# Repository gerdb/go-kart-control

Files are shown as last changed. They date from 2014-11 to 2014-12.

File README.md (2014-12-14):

#Go-Kart Control  
####Radio controlled displays for go-kart tracks  
---
 
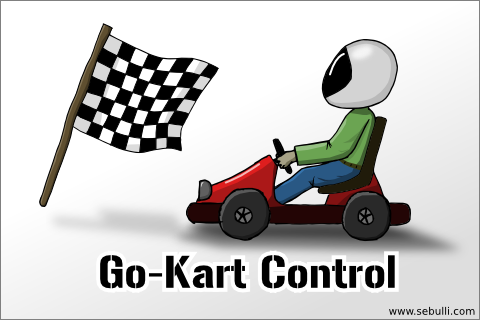
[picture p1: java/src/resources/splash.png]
slpash


##Install the Go-Kart-Control software
Download and unzip the ZIP archive containing all executables and also the source code:  
https://github.com/gerdb/go-kart-control/archive/master.zip  
On a windows system just start the executable **Go-Kart-Control.exe** in /install/win32 or win64  
On a Mac or Linux start the java JAR archive in install/all with **java - jar go-kart-control.jar**.  
Don't forget to set the correct serial port in settings.txt.  
Java must be installed: https://www.java.com/de/download/  

##Translation
You can translate the application.  
Open the *lang/messages.pot* file and translate it with http://poedit.net/  
Save the *messages_LANGUAGE_CODE.po* file in the *lang* folder of your program.  
Set the local code in *settings.txt*, if you don't want to use the system settings.

##Arduino software
If it's a new AVR, program it with the Arduino bootloader. For example with AVRDUDE:  
`avrdude -pm32u4 -cstk500 -P/dev/ttyUSB0 -e`  
`avrdude -pm32u4 -cstk500 -P/dev/ttyUSB0 -v -e -U lfuse:w:0xff:m -U hfuse:w:0xd8:m -U efuse:w:0xcb:m`  
`avrdude -pm32u4 -cstk500 -P/dev/ttyUSB0 -v -e -U flash:w:Caterina-Micro.hex -U lock:w:0x2F:m`

The Arduino project file is: **arduino/go_kart_panel/go_kart_panel.ino**

##Hardware setup
The PCB can be assembles in 2 variants: As a master module or as a panel module.  
The master module is connected to the PC.  
The panel module has a display.
The differences between both electronics are marked here:  
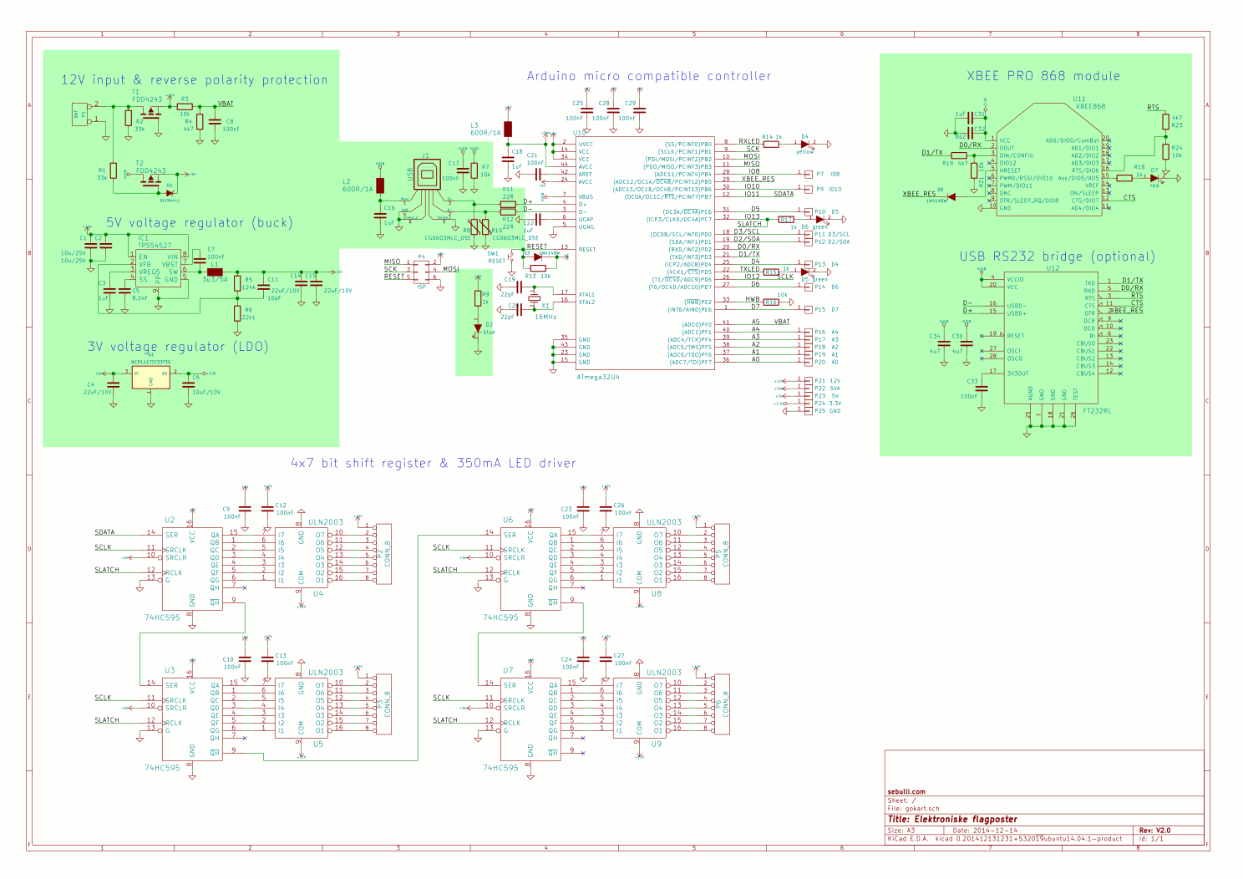
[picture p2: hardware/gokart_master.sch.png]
  
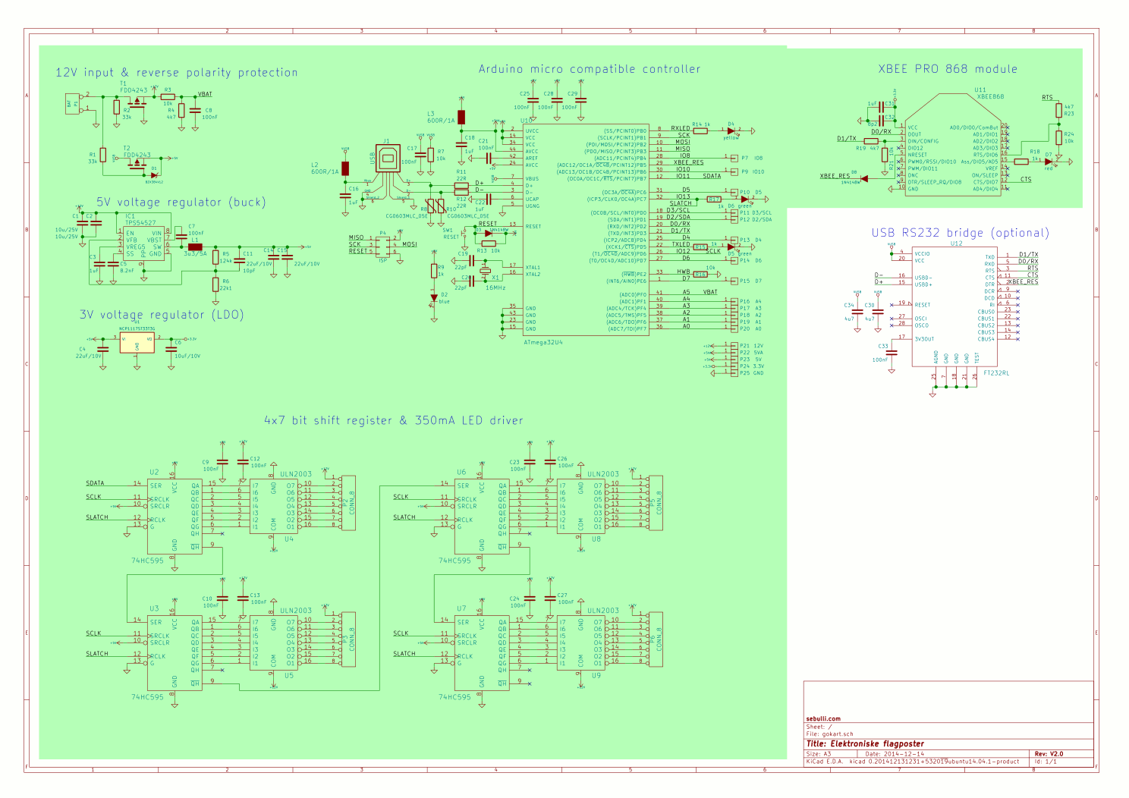
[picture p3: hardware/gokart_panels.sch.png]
  

###PCB layout
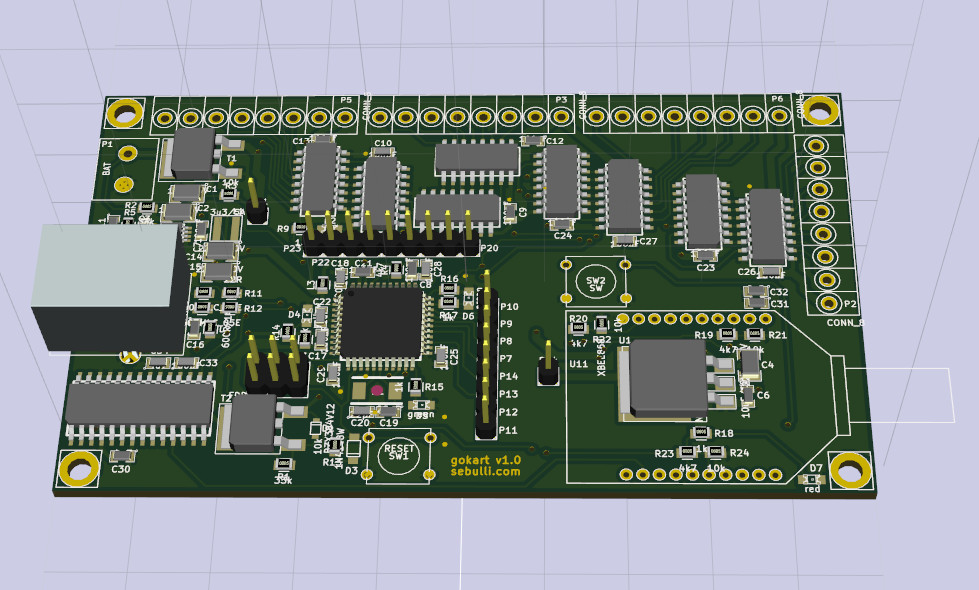
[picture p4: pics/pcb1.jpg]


###Master module
The master module is connected to a USB port of a PC or notebook. The master module can be supplied by USB or by an external 12V power supply. An external power supply is recommended on high power settings (If not, the blue LED is flickering). 

###Panel module
If there is a new master module, update the radio.ino file with the master's XBee address and download it to all panel modules. The panels will only accept data from this master.   
On startup, the software version, the battery voltage (120=12V) and the power setting (0..4) is displayed.  
The XBee module is ready when all LEDs blink for a short time.  
If then the testpoint P11 and P12 are connected together, the module displays the XBee address step by step and a display test is performed. Use this address to update the **settings.txt**  

Use 7-segment displays with common anode. Voltage is 12V. Use external resistors in each line **a**..**g**  
Connect LEDs to display the flag status. Connect the anode together.  
The maximum current for 7-segment display or LED is 300mA per line.

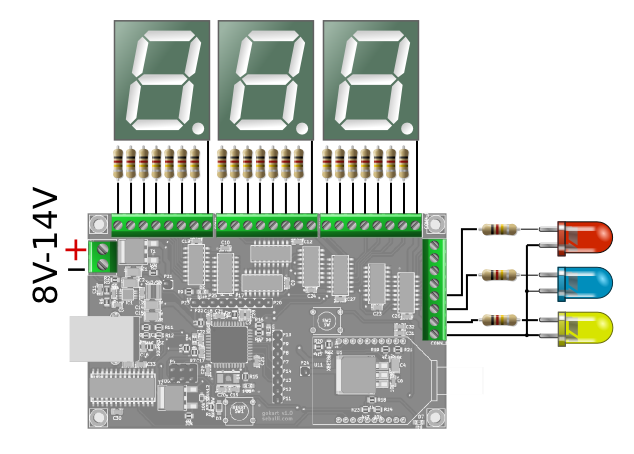
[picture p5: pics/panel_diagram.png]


##Your own Go-Kart track
You can use the /pics/track.svg to generate you own background images for your go-kart tracks.  
Edit this with Inkscape https://inkscape.org/de/ and export it as bitmap to your /pics folder. Filename is background.png.  
Edit the settings.txt and change the x and y position of your panels.  

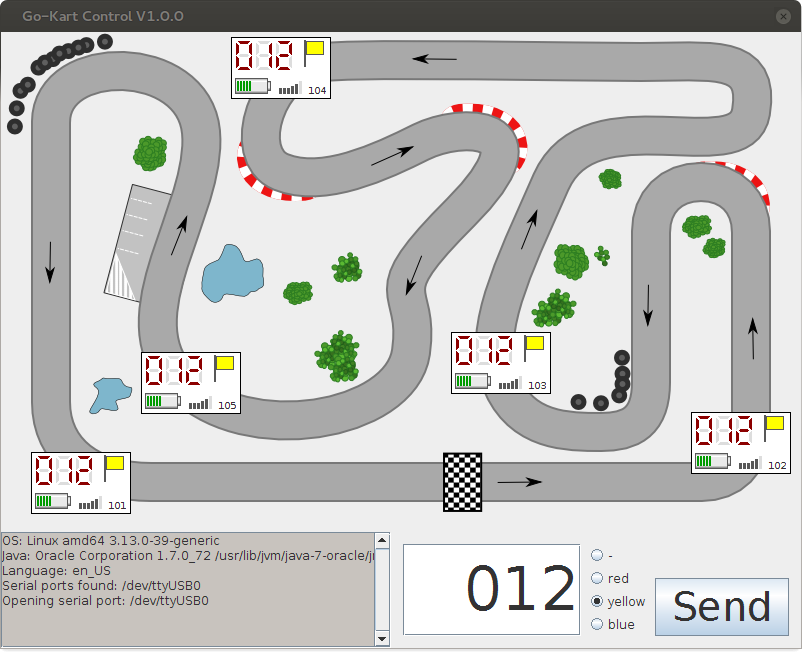
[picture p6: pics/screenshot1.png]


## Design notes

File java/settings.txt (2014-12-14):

# Configuration file for Go-kart control

# Set the language and country. For example to: da_DK.
# Leave it empty to use the system settings
locale :

# Set to 1, if main window should be always on top.
# Else set it to 0.
window.ontop : 0

# Set serial port
# For Windows it's something like COM1. See device manager.
# For Linux it's something like: ttyUSB0. See folder /dev/
port : ttyUSB0

# Enable the test mode
# 0: This value should set to 0, for normal operation
# 1: Test mode enabled. The RSSI value is displayed
testmode : 0

# Battery voltage
# The lower (empty) and upper limit (full) for battery voltage.
# Unit is volts.
battery.empty : 10.0
battery.full  : 13.5

# Signal strength indicator
# Unit is dbm
signal.poor : -110
signal.good : -60

# What to do, if send button was clicked
# nothing: Just send
# number : Clear the number field
# flag   : Clear the flag field
# all    : Clear both, number field and flag field
button.send.clear : all

# Time in seconds between 2 cycles of communicate with all panels
communication.pause : 0

# How many times should a transmission be repeated
communication.repeat : 3

# Set the power level from 0 .. 4  (0=1mW, 1=23mW, 2=100mW, 3=158mW, 4=316mW)
communication.power : 4

# If a panel does not receive a signal during this amount of cycles, the display is switched off
communication.timeout : 3

# Amount of panels
panels.amount : 6

# Configure each panel
# .name   Name of the panel (or number)
# .serial Radio serial number high and low
# .x       X-position
# .y       Y-position
# .vcorr   Battery voltage calibration value. (default: 1.00000)
# .enabled 1, if module is active, 0 if not

panels.1.name    : 001
panels.1.serial  : 0013A200 40A28F4A
panels.1.x       : 30
panels.1.y       : 420
panels.1.vcorr   : 0.995
panels.1.enabled : 1

panels.2.name    : 002
panels.2.serial  : 0013A200 40A28F4B
panels.2.x       : 690
panels.2.y       : 380
panels.2.vcorr   : 1.00
panels.2.enabled : 1

panels.3.name    : 003
panels.3.serial  : 0013A200 00000000
panels.3.x       : 450
panels.3.y       : 300
panels.3.vcorr   : 0.995
panels.3.enabled : 0

panels.4.name    : 004
panels.4.serial  : 0013A200 00000000
panels.4.x       : 230
panels.4.y       : 5
panels.4.vcorr   : 0.995
panels.4.enabled : 0

panels.5.name    : 005
panels.5.serial  : 0013A200 00000000
panels.5.x       : 140
panels.5.y       : 320
panels.5.vcorr   : 0.995
panels.5.enabled : 0

panels.6.name    : 006
panels.6.serial  : 0013A200 00000000
panels.6.x       : 60
panels.6.y       : 20
panels.6.vcorr   : 1.015
panels.6.enabled : 0

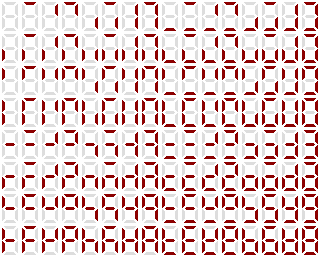
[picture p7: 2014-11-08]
java/src/resources/7segment.png

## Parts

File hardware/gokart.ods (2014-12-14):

Id | Designator | Package | Quantity | Designation | Reichelt | Farnell | Mouser
1 | C1,C2 | SMD_Packages:SMD-1210 | 2 | 10u/25V | X7R-G1210 10 0,47 | 1358512 0,39
2 | C3,C16,C18,C22,C31 | SMD_Packages:SMD-0805 | 5 | 1uF |  | 2320857 0,025
3 | C5 | SMD_Packages:SMD-0805 | 1 | 8.2nF |  | 2332807 0,13
4 | C6 | SMD_Packages:SMD-0805 | 1 | 10uF/10V |  | 2320851 0,11
5 | C7,C8,C9,C10,C12,C13,C17,C21,C23,C24,C25,C26,C27,C28,C29,C33 | SMD_Packages:SMD-0805 | 16 | 100nF |  | 2320839 0,22
6 | C11 | SMD_Packages:SMD-0805 | 1 | 10pF |  | 2320834 0,02
7 | C14,C15,C4 | SMD_Packages:SMD-1210 | 3 | 22uF/10V | X5R-G1210 22 0,26 | 2320951 0,63
8 | C19,C20 | SMD_Packages:SMD-0805 | 2 | 22pF |  | 1759271 0,02
9 | C30,C34 | SMD_Packages:SMD-0805 | 2 | 4u7 |  | 2320858 0,12
10 | C32 | SMD_Packages:SMD-0805 | 1 | 8p2 |  | 2332712 0,2
11 | D2 | LEDs:LED-0805 | 1 | blue |  | 2217974 0,2
12 | D4 | LEDs:LED-0805 | 1 | yellow |  | 2099242 0,08
13 | D5,D6 | LEDs:LED-0805 | 2 | green |  | 2099239 0,08
14 | D7 | LEDs:LED-0805 | 1 | red |  | 2099236 0,08
15 | J1 | Connect:USB_B | 1 | USB | USB BW 0,22 | 1696537 0,64
16 | L1 | My:L_XAL4030 | 1 | 3u3/5A |  | 2289055 1,04
17 | L2,L3 | Resistors_SMD:R_0805 | 2 | 600R/1A |  | 1669735 0,084
18 | P1 | My:LP_KLEMME_5.08_2 | 1 | BAT | AKL 101-02 0,31
19 | P4 | Pin_Headers:Pin_Header_Straight_2x03 | 1 | ISP | MPE 087-2-006 0,15
20 | P7 | Pin_Headers:Pin_Header_Straight_1x01 | 1 | IO8
34 | R1,R2 | Resistors_SMD:R_0805 | 2 | 33k |  | 9234195 0,006
35 | R3,R7,R13,R16,R21,R24 | Resistors_SMD:R_0805 | 7 | 10k |  | 2008390 0,018
36 | R4,R19,R23 | Resistors_SMD:R_0805 | 4 | 4k7 |  | 2073784 0,009
37 | R5 | Resistors_SMD:R_0805 | 1 | 124k |  | 2139036 0,008
38 | R6 | Resistors_SMD:R_0805 | 1 | 22k1 |  | 2057642 0,023
39 | R8,R10 | R0603 | 2 | CG0603MLC_05E |  |  | 652-CG0603MLC-05E 0,16
40 | R9,R14,R15,R17,R18 | Resistors_SMD:R_0805 | 5 | 1k |  | 9237496 0,006
41 | R11,R12 | Resistors_SMD:R_0805 | 2 | 22R |  | 9332847 0,016
42 | SW1 | Discret:SW_PUSH_SMALL | 1 | RESET | TASTER 3301D 0,11
44 | T1,T2 | SMD_Packages:DPAK-3_GDS | 2 | FDD4243 |  |  | 512-FDD4243 0,556
45 | U1 | SMD_Packages:DPAK-3 | 1 | NCP1117ST33T3G |  | 1652364 0,477
46 | U2,U3,U6,U7 | SMD_Packages:SO-16-N | 4 | 74HC595 | SMD HC 595 0,19
47 | U4,U5,U8,U9 | SMD_Packages:SO-16-N | 4 | ULN2003 | ULN 2003 AD SMD 0,29
48 | U10 | SMD_Packages:TQFP-44 | 1 | ATmega32U4 |  | 2443182 5,21
49 | U11 | My:XBEE_PRO_868 | 1 | XBEE868 | 2xBL 1X10G 2,00 0,23 |  | 2x888-XBP08-DPWIT-024 1x860-XBP08-DPSIT-024 1x888-A08-HASM-560
50 | U12 | SSOP-28 | 1 | FT232RL | FT 232 RL 2,95 |  | 895-FT232RL 3,77
51 | X1 | Crystals:Crystal_SMD_0603_2Pads_obsolete | 1 | 16MHz |  | 1841946 0,75
52 | D3,D8 | My:SOD-123 | 1 | 1N4148W |  | 1776392 0,18
53 | IC1 | SO8-PowerPad | 1 | TPS54527 |  |  | 595-TPS54527DDA 2,72
54 | P2,P3,P5,P6 | My:RIA_8_3.5_TYP59 | 4 | CONN_8 | AKL 059-08 0,95
55 | HOLE_M3,HOLE_M3,HOLE_M3,HOLE_M3 | My:HOLE_M3 | 4 | VAL**
56 | D1 | My:SOD-323 | 1 | BZX384V12 |  | 1431191 0,004
57 | P21 | Pin_Headers:Pin_Header_Straight_1x01 | 1 | 12V
58 | P22 | Pin_Headers:Pin_Header_Straight_1x01 | 1 | 5VA
 |  |  |  |  | AK 672/2-2,0 0,75
 |  |  |  |  | 3x SA 39-11 GN 0,64
 |  |  |  |  | LED 5-16000 RT 0,34
 |  |  |  |  | LED 5-14000 GE 0,26
 |  |  |  |  | LED 5-12000 BL 0,21
 |  |  |  |  | 10x 1/4W 2700 0,33
 |  |  |  |  | 100x 1/4W 510 0,019

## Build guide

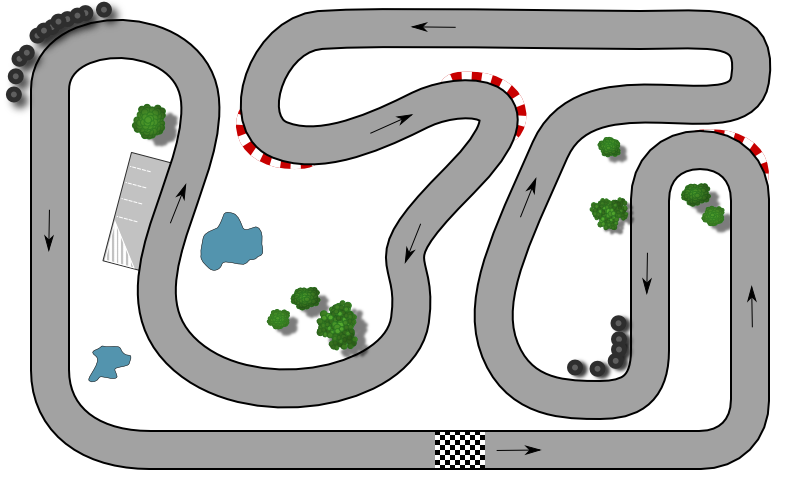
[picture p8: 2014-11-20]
install/win64/pics/background.png

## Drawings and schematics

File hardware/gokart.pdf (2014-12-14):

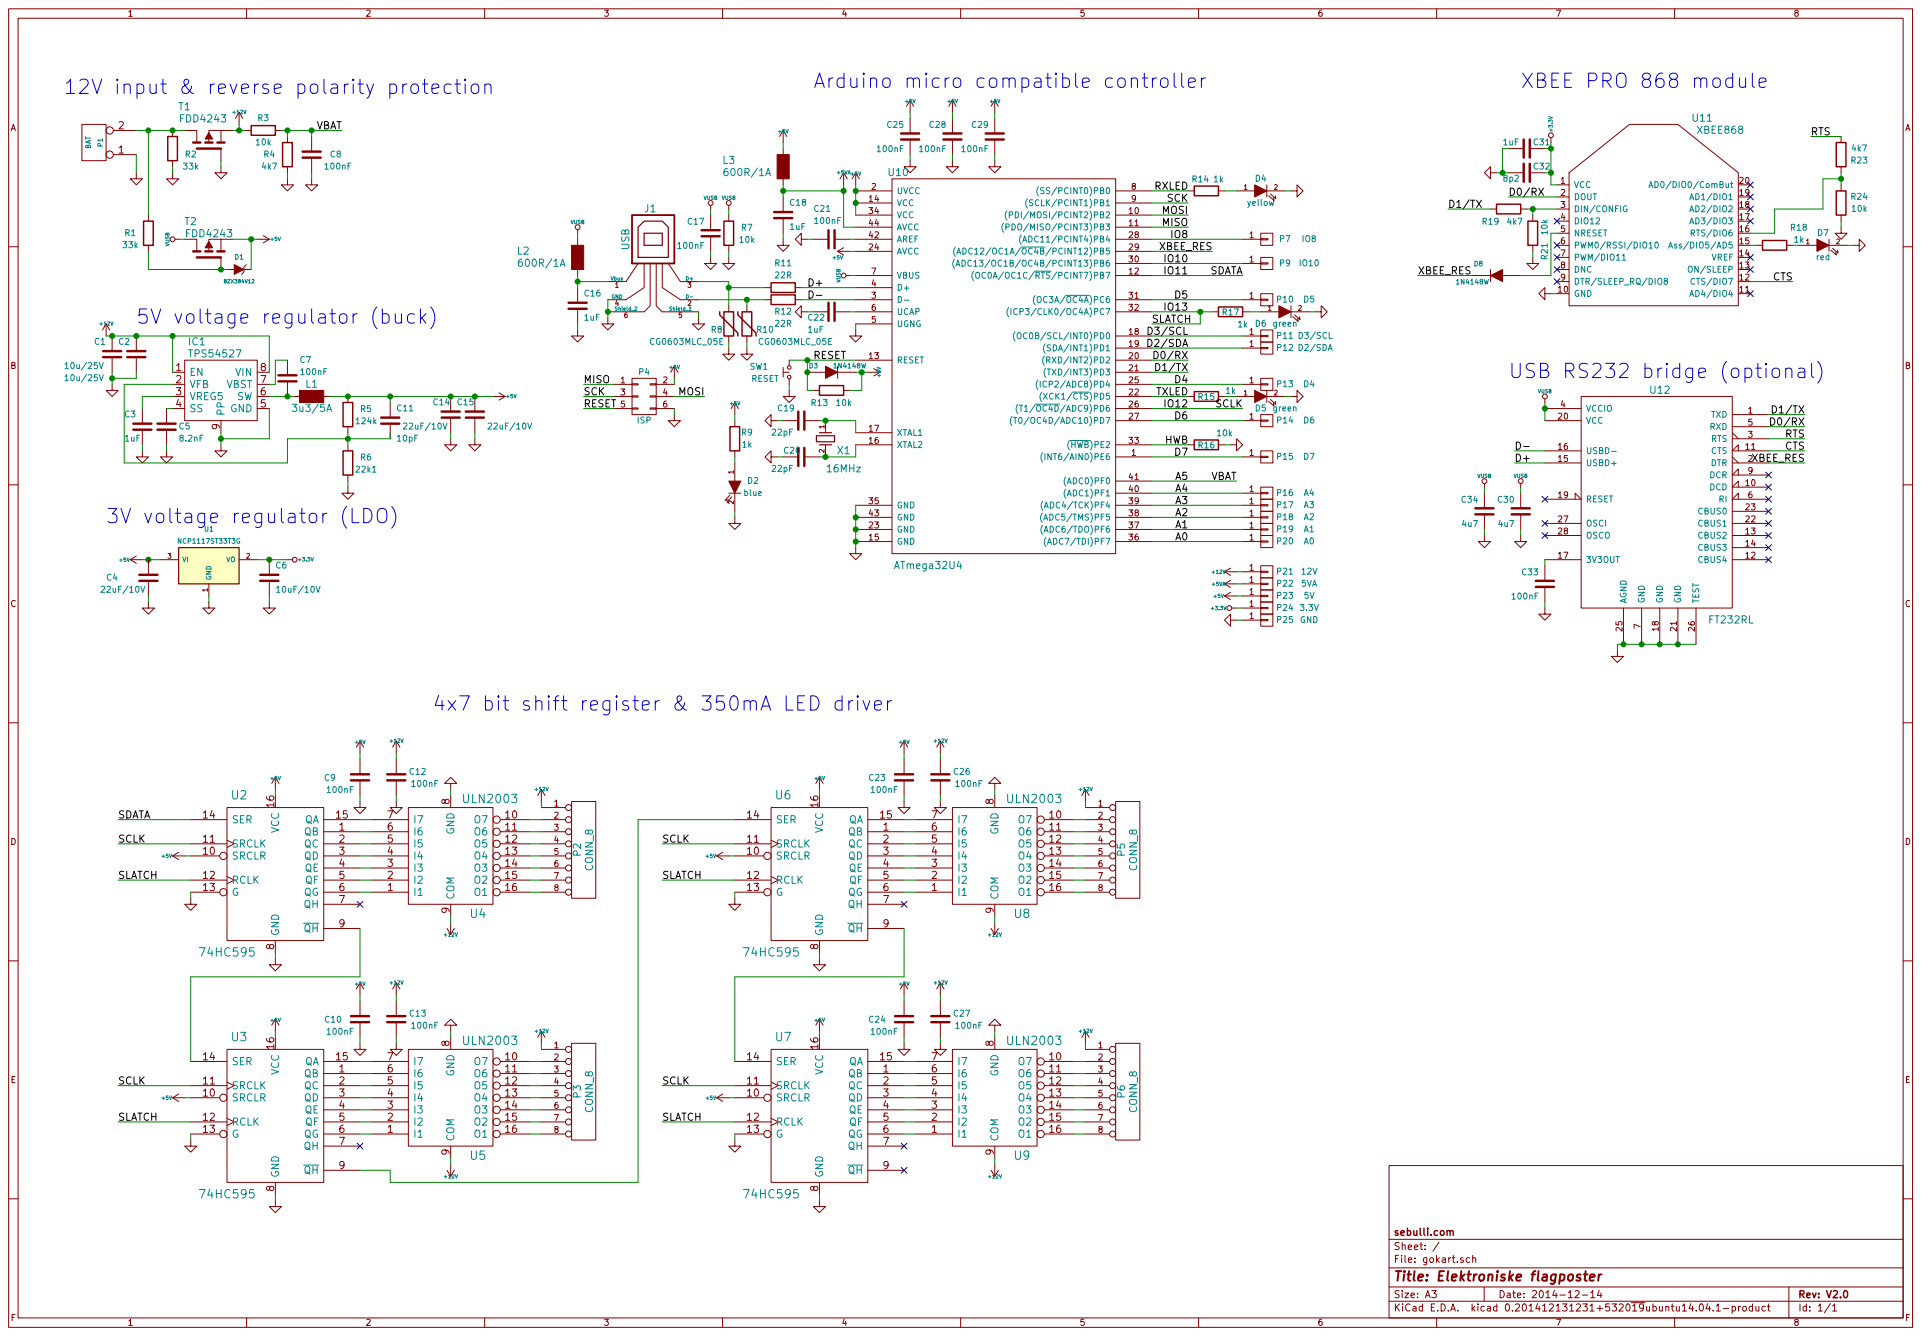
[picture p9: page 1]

+5V 12V input & reverse polarity protection

4x7 bit shift register & 350mA LED driver

8 QH 9 SRCLR 10 SRCLK 11 RCLK 12 G

File: gokart.sch Sheet: / sebulli.com

Id: 1/1 Title: Elektroniske flagposter

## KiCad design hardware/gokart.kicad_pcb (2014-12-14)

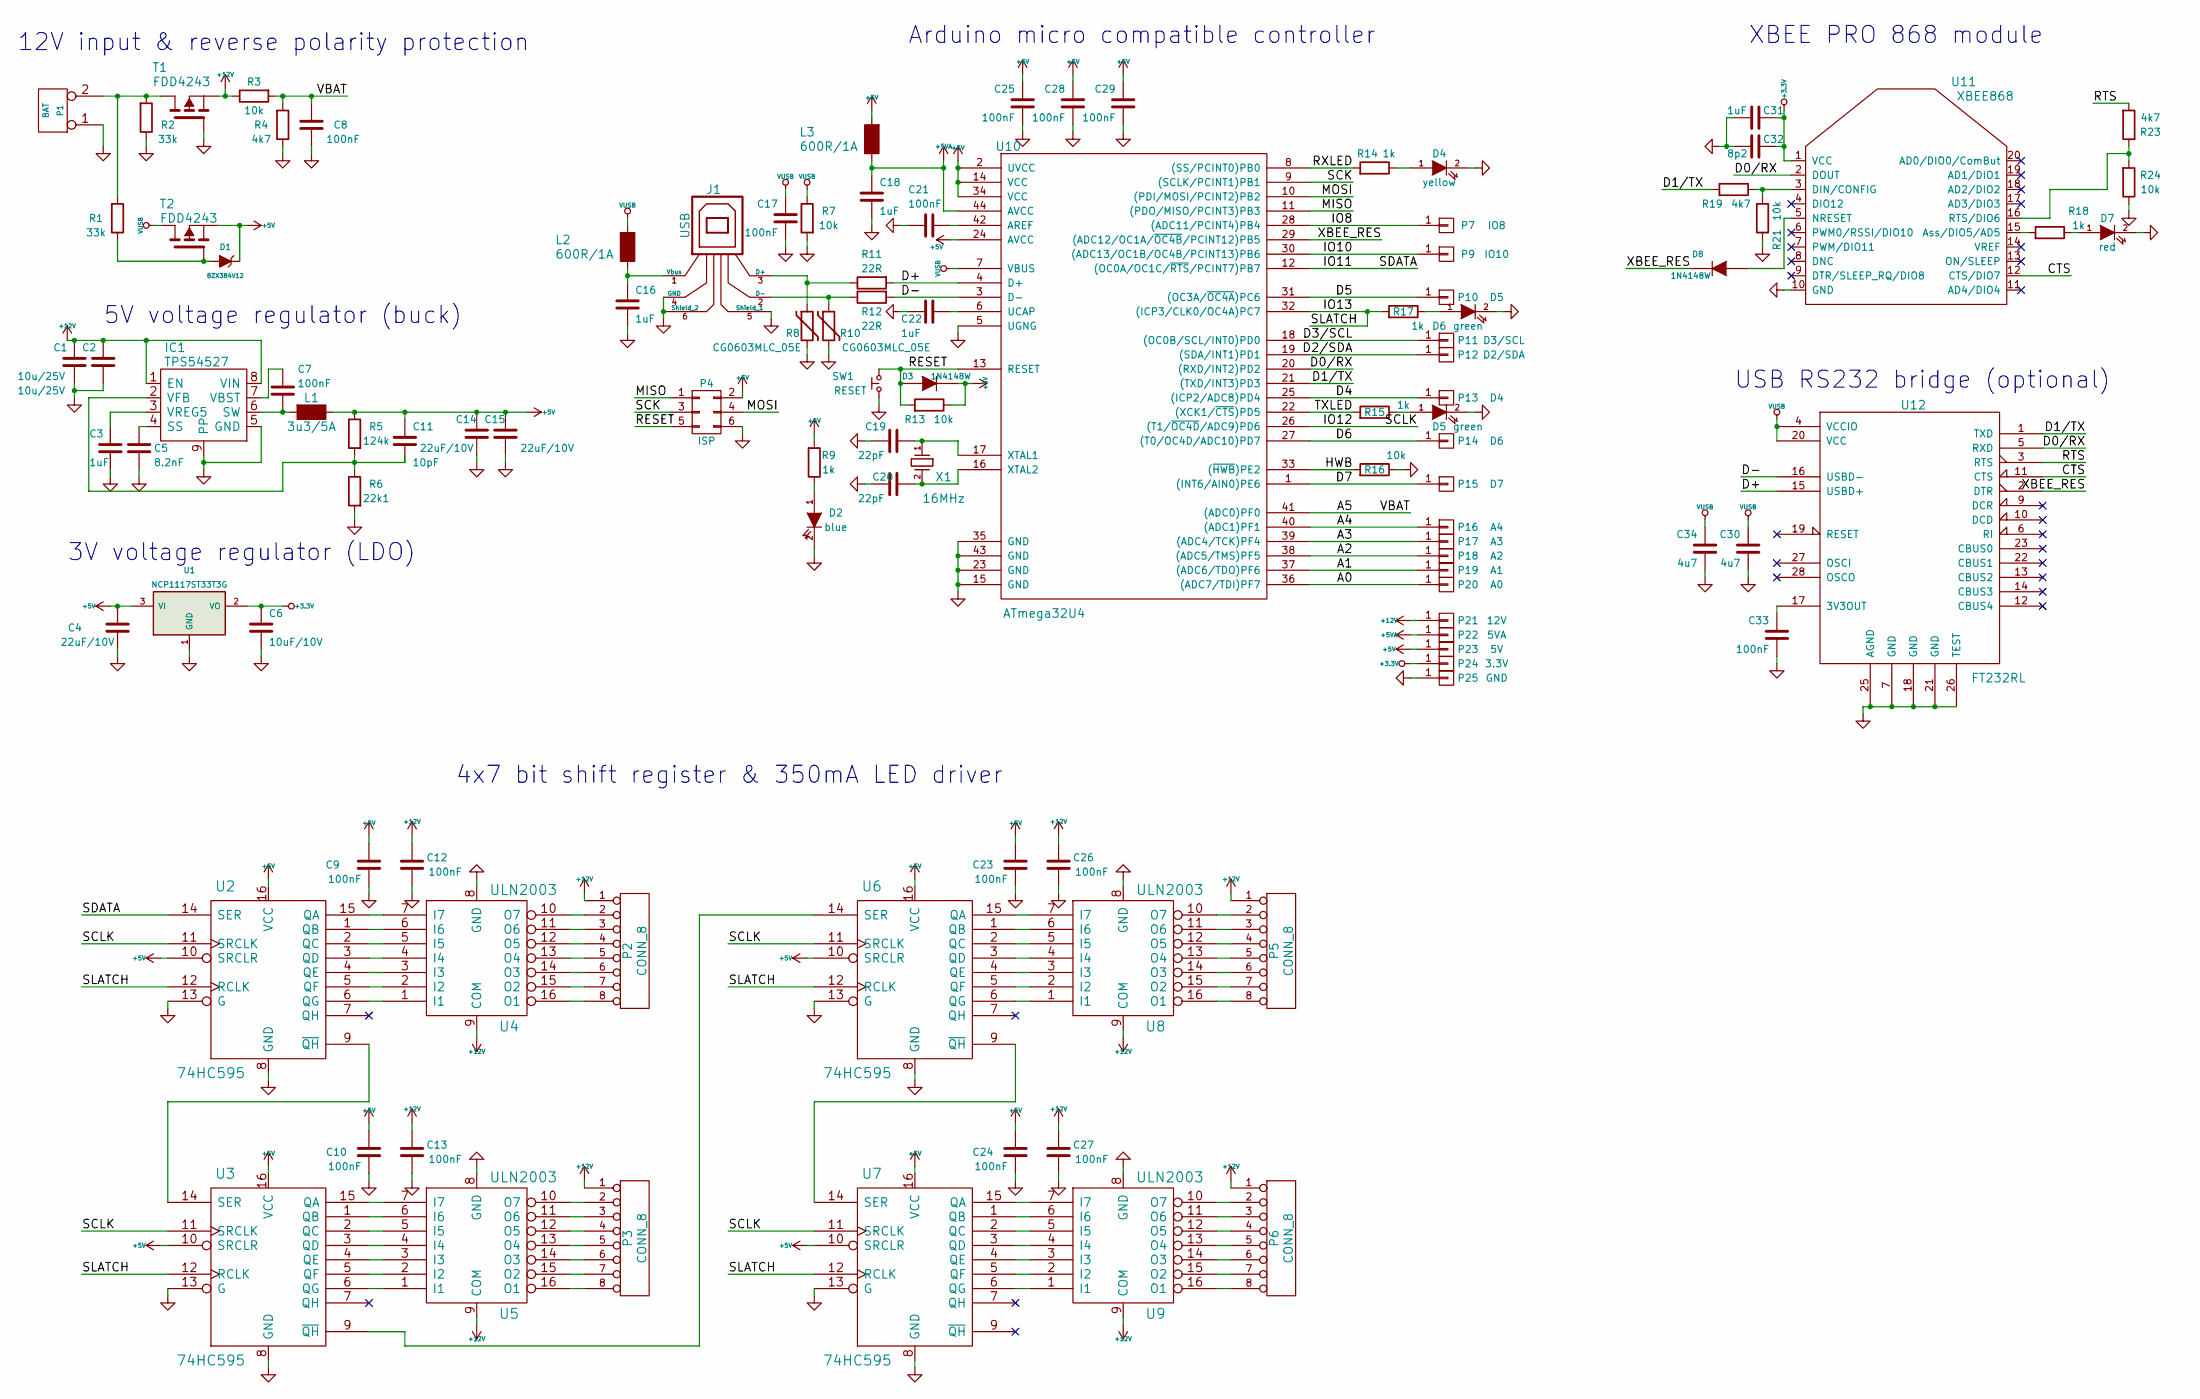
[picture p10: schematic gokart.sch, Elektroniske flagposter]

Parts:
C1, C2: 10u/25V; SMD-1210
C3, C16, C18, C22, C31: 1uF; SMD-0805
C4, C14, C15: 22uF/10V; SMD-1210
C5: 8.2nF; SMD-0805
C6: 10uF/10V; SMD-0805
C7, C8, C9, C10, C12, C13, C17, C21, C23, C24, C25, C26, C27, C28, C29, C33: 100nF; SMD-0805
C11: 10pF; SMD-0805
C19, C20: 22pF; SMD-0805
C30, C34: 4u7; SMD-0805
C32: 8p2; SMD-0805
D1: BZX384V12; SOD-323
D2: blue; LED-0805
D3, D8: 1N4148W; SOD-123
D4: yellow; LED-0805
D5, D6: green; LED-0805
D7: red; LED-0805
IC1: TPS54527; SOIC-8-N-1EP
J1: USB; USB_B
L1: 3u3/5A; L_XAL4030
L2, L3: 600R/1A; R_0805
P1: BAT; LP_KLEMME_5.08_2
P2, P3, P5, P6: CONN_8; RIA_8_3.5_TYP59
P4: ISP; Pin_Header_Straight_2x03
P7: IO8; Pin_Header_Straight_1x01
P9: IO10; Pin_Header_Straight_1x01
P10: D5; Pin_Header_Straight_1x01
P11: D3/SCL; Pin_Header_Straight_1x01
P12: D2/SDA; Pin_Header_Straight_1x01
P13: D4; Pin_Header_Straight_1x01
P14: D6; Pin_Header_Straight_1x01
P15: D7; Pin_Header_Straight_1x01
P16: A4; Pin_Header_Straight_1x01
P17: A3; Pin_Header_Straight_1x01
P18: A2; Pin_Header_Straight_1x01
P19: A1; Pin_Header_Straight_1x01
P20: A0; Pin_Header_Straight_1x01
P21: 12V; Pin_Header_Straight_1x01
P22: 5VA; Pin_Header_Straight_1x01
P23: 5V; Pin_Header_Straight_1x01
P24: 3.3V; Pin_Header_Straight_1x01
P25: GND; Pin_Header_Straight_1x01
R1, R2: 33k; R_0805
R3, R7, R13, R16, R21, R24: 10k; R_0805
R4, R19, R23: 4k7; R_0805
R5: 124k; R_0805
R6: 22k1; R_0805
R8, R10: CG0603MLC_05E; SMD-0603
R9, R14, R15, R17, R18: 1k; R_0805
R11, R12: 22R; R_0805
SW1: RESET; SW_PUSH_SMALL
T1, T2: FDD4243; DPAK-3_GDS
U1: NCP1117ST33T3G; DPAK-3
U2, U3, U6, U7: 74HC595; SO-16-N
U4, U5, U8, U9: ULN2003; SO-16-N
U10: ATmega32U4; TQFP-44
U11: XBEE868; XBEE_PRO_868
U12: FT232RL; SSOP-28
X1: 16MHz; Crystal_SMD_0603_2Pads_obsolete

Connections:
+3.3V: C6.1, C31.1, C32.1, P24.1, U1.2 (VO), U11.1 (VCC)
+5V: C4.1, C9.2, C10.2, C11.1, C14.1, C15.1, C23.2, C24.2, C25.2, C28.2, C29.2, D1.2 (K), D3.2 (K), L1.2, L3.1, P4.2, P23.1, R5.2, R9.1, R13.2, T2.S, U1.3 (VI), U2.10 (SRCLR), U2.16 (VCC), U3.10 (SRCLR), U3.16 (VCC), U6.10 (SRCLR), U6.16 (VCC), U7.10 (SRCLR), U7.16 (VCC), U10.2 (UVCC), U10.14 (VCC), U10.24 (AVCC), U10.34 (VCC)
+5VA: C18.1, L3.2, P22.1, U10.44 (AVCC)
+12V: C1.1, C2.1, C12.2, C13.2, C26.2, C27.2, IC1.1 (EN), IC1.8 (VIN), P2.1, P3.1, P5.1, P6.1, P21.1, R3.2, T1.S, U4.9 (COM), U5.9 (COM), U8.9 (COM), U9.9 (COM)
/A0: P20.1, U10.36 ((ADC7/TDI)PF7)
/A1: P19.1, U10.37 ((ADC6/TDO)PF6)
/A2: P18.1, U10.38 ((ADC5/TMS)PF5)
/A3: P17.1, U10.39 ((ADC4/TCK)PF4)
/A4: P16.1, U10.40 ((ADC1)PF1)
/A5: C8.1, R3.1, R4.1, U10.41 ((ADC0)PF0)
/CTS: U11.12 (CTS/DIO7), U12.11 (CTS)
/D0/RX: U10.20 ((RXD/INT2)PD2), U11.2 (DOUT), U12.5 (RXD)
/D1/TX: R19.1, U10.21 ((TXD/INT3)PD3), U12.1 (TXD)
/D2/SDA: P12.1, U10.19 ((SDA/INT1)PD1)
/D3/SCL: P11.1, U10.18 ((OC0B/SCL/INT0)PD0)
/D4: P13.1, U10.25 ((ICP2/ADC8)PD4)
/D5: P10.1, U10.31 ((OC3A/~OC4A~)PC6)
/D6: P14.1, U10.27 ((T0/OC4D/ADC10)PD7)
/D7: P15.1, U10.1 ((INT6/AIN0)PE6)
/D+: R11.1, U10.4 (D+), U12.15 (USBD+)
/D-: R12.1, U10.3 (D-), U12.16 (USBD-)
/HWB: R16.1, U10.33 ((~HWB~)PE2)
/IO8: P7.1, U10.28 ((ADC11/PCINT4)PB4)
/IO10: P9.1, U10.30 ((ADC13/OC1B/OC4B/PCINT13)PB6)
/IO11: U2.14 (SER), U10.12 ((OC0A/OC1C/~RTS~/PCINT7)PB7)
/IO12: U2.11 (SRCLK), U3.11 (SRCLK), U6.11 (SRCLK), U7.11 (SRCLK), U10.26 ((T1/~OC4D~/ADC9)PD6)
/IO13: R17.1, U2.12 (RCLK), U3.12 (RCLK), U6.12 (RCLK), U7.12 (RCLK), U10.32 ((ICP3/CLK0/OC4A)PC7)
/MISO: P4.1, U10.11 ((PDO/MISO/PCINT3)PB3)
/MOSI: P4.4, U10.10 ((PDI/MOSI/PCINT2)PB2)
/RESET: D3.1 (A), P4.5, R13.1, SW1.2, U10.13 (RESET)
/RTS: R23.1, U12.3 (RTS)
/RXLED: R14.1, U10.8 ((SS/PCINT0)PB0)
/SCK: P4.3, U10.9 ((SCLK/PCINT1)PB1)
/TXLED: R15.1, U10.22 ((XCK1/~CTS~)PD5)
/XBEE_RES: D8.2 (K), U10.29 ((ADC12/OC1A/~OC4B~/PCINT12)PB5), U12.2 (DTR)
GND: C1.2, C2.2, C3.2, C4.2, C5.2, C6.2, C8.2, C9.1, C10.1, C12.1, C13.1, C14.2, C15.2, C16.2, C17.1, C18.2, C19.2, C20.2, C21.2, C22.2, C23.1, C24.1, C25.1, C26.1, C27.1, C28.1, C29.1, C30.1, C31.2, C32.2, C33.1, C34.1, D2.2 (K), D4.2 (K), D5.2 (K), D6.2 (K), D7.2 (K), IC1.5 (GND), IC1.9 (PP), J1.4 (GND), J1.5 (Shield_1), J1.6 (Shield_2), P1.1, P4.6, P25.1, R2.2, R4.2, R6.1, R7.1, R8.2, R10.2, R16.2, R21.2, R24.2, SW1.1, T1.G, U1.1 (GND), U2.8 (GND), U2.13 (G), U3.8 (GND), U3.13 (G), U4.8 (GND), U5.8 (GND), U6.8 (GND), U6.13 (G), U7.8 (GND), U7.13 (G), U8.8 (GND), U9.8 (GND), U10.5 (UGNG), U10.15 (GND), U10.23 (GND), U10.35 (GND), U10.43 (GND), U11.10 (GND), U12.7 (GND), U12.18 (GND), U12.21 (GND), U12.25 (AGND), U12.26 (TEST)
unnamed: C3.1, IC1.3 (VREG5)
unnamed: C5.1, IC1.4 (SS)
unnamed: C7.1, IC1.7 (VBST)
unnamed: C7.2, IC1.6 (SW), L1.1
unnamed: C11.2, IC1.2 (VFB), R5.1, R6.2
unnamed: C16.1, J1.1 (Vbus), L2.2
unnamed: C19.1, U10.17 (XTAL1), X1.1
unnamed: C20.1, U10.16 (XTAL2), X1.2
unnamed: C21.1, U10.42 (AREF)
unnamed: C22.1, U10.6 (UCAP)
unnamed: C33.2, U12.17 (3V3OUT)
unnamed: D1.1 (A), R1.2, T2.G
unnamed: D2.1 (A), R9.2
unnamed: D4.1 (A), R14.2
unnamed: D5.1 (A), R15.2
unnamed: D6.1 (A), R17.2
unnamed: D7.1 (A), R18.2
unnamed: D8.1 (A), U11.5 (NRESET)
unnamed: J1.2 (D-), R10.1, R12.2
unnamed: J1.3 (D+), R8.1, R11.2
unnamed: P1.2 (PM), R1.1, R2.1, T1.D
unnamed: P2.2, U4.10 (O7)
unnamed: P2.3, U4.11 (O6)
unnamed: P2.4, U4.12 (O5)
unnamed: P2.5, U4.13 (O4)
unnamed: P2.6, U4.14 (O3)
unnamed: P2.7, U4.15 (O2)
unnamed: P2.8, U4.16 (O1)
unnamed: P3.2, U5.10 (O7)
unnamed: P3.3, U5.11 (O6)
unnamed: P3.4, U5.12 (O5)
unnamed: P3.5, U5.13 (O4)
unnamed: P3.6, U5.14 (O3)
unnamed: P3.7, U5.15 (O2)
unnamed: P3.8, U5.16 (O1)
unnamed: P5.2, U8.10 (O7)
unnamed: P5.3, U8.11 (O6)
unnamed: P5.4, U8.12 (O5)
unnamed: P5.5, U8.13 (O4)
unnamed: P5.6, U8.14 (O3)
unnamed: P5.7, U8.15 (O2)
unnamed: P5.8, U8.16 (O1)
unnamed: P6.2, U9.10 (O7)
unnamed: P6.3, U9.11 (O6)
unnamed: P6.4, U9.12 (O5)
unnamed: P6.5, U9.13 (O4)
unnamed: P6.6, U9.14 (O3)
unnamed: P6.7, U9.15 (O2)
unnamed: P6.8, U9.16 (O1)
unnamed: R18.1, U11.15 (Ass/DIO5/AD5)
unnamed: R19.2, R21.1, U11.3 (DIN/CONFIG)
unnamed: R23.2, R24.1, U11.16 (RTS/DIO6)
unnamed: U2.1 (QB), U4.6 (I6)
unnamed: U2.2 (QC), U4.5 (I5)
unnamed: U2.3 (QD), U4.4 (I4)
unnamed: U2.4 (QE), U4.3 (I3)
unnamed: U2.5 (QF), U4.2 (I2)
unnamed: U2.6 (QG), U4.1 (I1)
unnamed: U2.9 (~QH), U3.14 (SER)
unnamed: U2.15 (QA), U4.7 (I7)
unnamed: U3.1 (QB), U5.6 (I6)
unnamed: U3.2 (QC), U5.5 (I5)
unnamed: U3.3 (QD), U5.4 (I4)
unnamed: U3.4 (QE), U5.3 (I3)
unnamed: U3.5 (QF), U5.2 (I2)
unnamed: U3.6 (QG), U5.1 (I1)
unnamed: U3.9 (~QH), U6.14 (SER)
unnamed: U3.15 (QA), U5.7 (I7)
unnamed: U6.1 (QB), U8.6 (I6)
unnamed: U6.2 (QC), U8.5 (I5)
unnamed: U6.3 (QD), U8.4 (I4)
unnamed: U6.4 (QE), U8.3 (I3)
unnamed: U6.5 (QF), U8.2 (I2)
unnamed: U6.6 (QG), U8.1 (I1)
unnamed: U6.9 (~QH), U7.14 (SER)
unnamed: U6.15 (QA), U8.7 (I7)
unnamed: U7.1 (QB), U9.6 (I6)
unnamed: U7.2 (QC), U9.5 (I5)
unnamed: U7.3 (QD), U9.4 (I4)
unnamed: U7.4 (QE), U9.3 (I3)
unnamed: U7.5 (QF), U9.2 (I2)
unnamed: U7.6 (QG), U9.1 (I1)
unnamed: U7.15 (QA), U9.7 (I7)
VUSB: C17.2, C30.2, C34.2, L2.1, R7.2, T2.D, U10.7 (VBUS), U12.4 (VCCIO), U12.20 (VCC)

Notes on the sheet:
12V input & reverse polarity protection
5V voltage regulator (buck)
3V voltage regulator (LDO)
Arduino micro compatible controller
XBEE PRO 868 module
USB RS232 bridge (optional)
4x7 bit shift register & 350mA LED driver

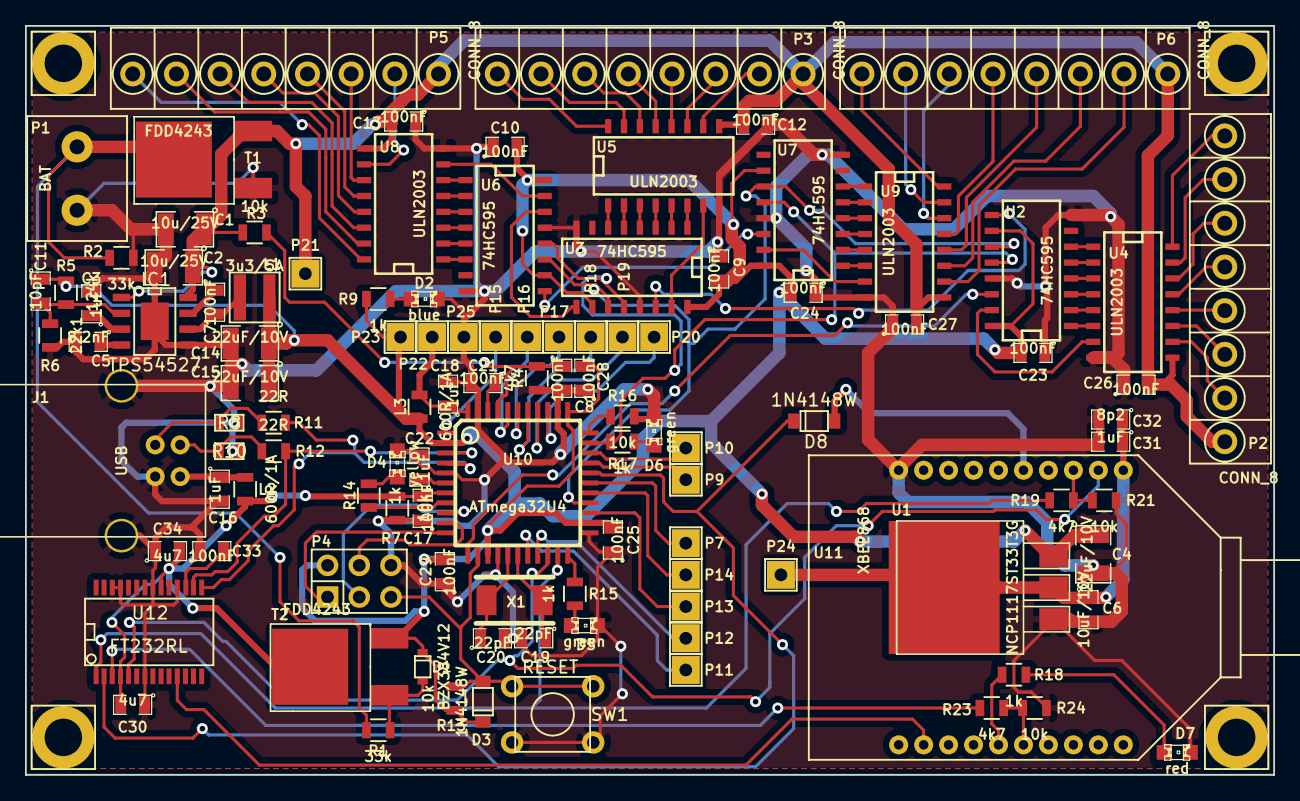
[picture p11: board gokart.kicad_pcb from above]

Board: 2 copper layers, 100.0 x 60.0 mm, 113 parts (0 on the bottom side), 120 nets.

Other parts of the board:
HOLE_M3, HOLE_M3#2, HOLE_M3#3, HOLE_M3#4: VAL**; HOLE_M3

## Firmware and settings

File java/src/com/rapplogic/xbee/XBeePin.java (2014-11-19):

/**
 * Copyright (c) 2009 Andrew Rapp. All rights reserved.
 *  
 * This file is part of XBee-API.
 *  
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
 * You should have received a copy of the GNU General Public License
 * along with XBee-API.  If not, see <http://www.gnu.org/licenses/>.
 */

package com.rapplogic.xbee;

import java.util.ArrayList;
import java.util.Collections;
import java.util.Comparator;
import java.util.List;

/**
 * Represents a configurable XBee pin and associated name, pin number, AT command, default capability and list of supported 
 * capabilities.
 * 
 * @author andrew
 *
 */
@SuppressWarnings("unchecked")
public class XBeePin {

//TODO add pin direction
//TODO methods to filter list by Capability
	 
	private String name;
	private Integer pin;
	private String atCommand;
	private Integer atPin;
	// TODO add logical pin e.g. getDigital(pin)
	
	private Capability defaultCapability;
	private String description;

	private List<Capability> capabilities = new ArrayList<Capability>();
	
	/**
	 * Contains all possible pin configurations and the associated AT command value
	 * 
	 * @author andrew
	 *
	 */
	public enum Capability {
		DISABLED (0),
		RTS_FLOW_CTRL(1),
		CTS_FLOW_CTRL(1),
		RSSI_PWM (1),
		ASSOC_LED (1),
		ANALOG_INPUT (2),
		PWM_OUTPUT (2),
		DIGITAL_INPUT (3),
		DIGITAL_OUTPUT_LOW (4),
		DIGITAL_OUTPUT_HIGH (5),
		UNMONITORED_INPUT (0), // only zigbee
		NODE_ID_ENABLED (1), // only zigbee
		RS485_TX_LOW(6), // only zigbee
		RS485_TX_HIGH(7); // only zigbee		
	
	    private final int value;
	    
	    Capability(int value) {
	        this.value = value;
	    }

		public int getValue() {
			return value;
		}
		
		public static String printAll(String delimiter) {
			StringBuffer sb = new StringBuffer();
			
			for (Capability cap : Capability.values()) {
				sb.append(System.getProperty("line.separator"));
				sb.append(delimiter);
				sb.append(cap);
				sb.append(delimiter);
				sb.append("0x" + cap.getValue());
				sb.append(cap.getValue());
				sb.append(delimiter);
			}
			
			return sb.toString();
		}
	}
	
	public XBeePin(String name, Integer pin, String atCommand, Integer atPin, Capability defaultCapability, String description, Capability... capabilityArr) {
		this.setName(name);
		this.setPin(pin);
		this.setAtCommand(atCommand);
		this.setAtPin(atPin);
		this.setDefaultCapability(defaultCapability);
		this.setDescription(description);
		
		if (capabilityArr != null) {
			for (Capability capability: capabilityArr) {
				this.getCapabilities().add(capability);
			}			
		}
	}

	public String getName() {
		return name;
	}

	public void setName(String name) {
		this.name = name;
	}

	public Integer getPin() {
		return pin;
	}

	public void setPin(Integer pin) {
		this.pin = pin;
	}

	public String getAtCommand() {
		return atCommand;
	}

	public void setAtCommand(String atCommand) {
		this.atCommand = atCommand;
	}

	public Capability getDefaultCapability() {
		return defaultCapability;
	}

	public void setDefaultCapability(Capability defaultCapability) {
		this.defaultCapability = defaultCapability;
	}

	public String getDescription() {
		return description;
	}

	public void setDescription(String description) {
		this.description = description;
	}

	public List<Capability> getCapabilities() {
		return capabilities;
	}

	public void setCapabilities(List<Capability> capabilities) {
		this.capabilities = capabilities;
	}
	
	public Integer getAtPin() {
		return atPin;
	}

	public void setAtPin(Integer atPin) {
		this.atPin = atPin;
	}
	
	private final static List<XBeePin> zigBeePins = new ArrayList<XBeePin>();
	
	static {
		// notes: DIO13/DIO8/DIO9 not supported
		// TODO P0/P1 is missing pwm output option?? could it be 0x2?
		zigBeePins.add(new XBeePin("PWM0/RSSI/DIO10", 6, "P0", 10, Capability.RSSI_PWM, "PWM Output 0 / RX Signal Strength Indicator / Digital IO", 
				Capability.DISABLED, Capability.RSSI_PWM, Capability.DIGITAL_INPUT, Capability.DIGITAL_OUTPUT_LOW, 
				Capability.DIGITAL_OUTPUT_HIGH));
		zigBeePins.add(new XBeePin("PWM/DIO11", 7, "P1", 1, Capability.UNMONITORED_INPUT, "Digital I/O 11", Capability.UNMONITORED_INPUT, 
				Capability.DIGITAL_INPUT, Capability.DIGITAL_OUTPUT_LOW, Capability.DIGITAL_OUTPUT_HIGH));
		zigBeePins.add(new XBeePin("DIO12", 4, "P2", 2, Capability.UNMONITORED_INPUT, "Digital I/O 12", Capability.UNMONITORED_INPUT, 
				Capability.DIGITAL_INPUT, Capability.DIGITAL_OUTPUT_LOW, Capability.DIGITAL_OUTPUT_HIGH));
		zigBeePins.add(new XBeePin("AD0/DIO0/Commissioning Button", 20, "D0", 0, Capability.NODE_ID_ENABLED, 
				"Analog Input 0, Digital IO 0, or Commissioning Button", Capability.DISABLED, Capability.NODE_ID_ENABLED, 
				Capability.ANALOG_INPUT, Capability.DIGITAL_INPUT, Capability.DIGITAL_OUTPUT_LOW, Capability.DIGITAL_OUTPUT_HIGH));
		zigBeePins.add(new XBeePin("AD1/DIO1", 19, "D1", 1, Capability.DISABLED, "Analog Input 1 or Digital I/O 1", Capability.DISABLED, 
				Capability.ANALOG_INPUT, Capability.DIGITAL_INPUT, Capability.DIGITAL_OUTPUT_LOW, Capability.DIGITAL_OUTPUT_HIGH));
		zigBeePins.add(new XBeePin("AD2/DIO2", 18, "D2", 2, Capability.DISABLED, "Analog Input 2 or Digital I/O 2", Capability.DISABLED, 
				Capability.ANALOG_INPUT, Capability.DIGITAL_INPUT, Capability.DIGITAL_OUTPUT_LOW, Capability.DIGITAL_OUTPUT_HIGH));
		zigBeePins.add(new XBeePin("AD3/DIO3", 17, "D3", 3, Capability.DISABLED, "Analog Input 3 or Digital I/O 3", Capability.DISABLED, 
				Capability.ANALOG_INPUT, Capability.DIGITAL_INPUT, Capability.DIGITAL_OUTPUT_LOW, Capability.DIGITAL_OUTPUT_HIGH));
		zigBeePins.add(new XBeePin("DIO4", 11, "D4", 4, Capability.DISABLED, "Digital I/O 4", Capability.DISABLED, Capability.DIGITAL_INPUT, Capability.DIGITAL_OUTPUT_LOW, Capability.DIGITAL_OUTPUT_HIGH));
		zigBeePins.add(new XBeePin("Associate/DIO5", 15, "D5", 5, Capability.ASSOC_LED, "Associated Indicator, Digital I/O 5", 
				Capability.DISABLED, Capability.ASSOC_LED, Capability.DIGITAL_INPUT, Capability.DIGITAL_OUTPUT_LOW, 
				Capability.DIGITAL_OUTPUT_HIGH));
		zigBeePins.add(new XBeePin("CTS/DIO7", 12, "D7", 7, Capability.CTS_FLOW_CTRL, "Clear-to-Send Flow Control or Digital I/O 7", 
				Capability.DISABLED, Capability.CTS_FLOW_CTRL, Capability.DIGITAL_INPUT, Capability.DIGITAL_OUTPUT_LOW, 
				Capability.DIGITAL_OUTPUT_HIGH, Capability.RS485_TX_LOW, Capability.RS485_TX_HIGH));
		
		// TODO manual lists only RTS and disabled but x-ctu lists all digital capabilities
		zigBeePins.add(new XBeePin("RTS/DIO6", 16, "D6", 6, Capability.DISABLED, "Request-to-Send Flow Control, Digital I/O 6", 
				Capability.DISABLED, Capability.RTS_FLOW_CTRL, Capability.DIGITAL_INPUT, Capability.DIGITAL_OUTPUT_LOW, 
				Capability.DIGITAL_OUTPUT_HIGH));
		
		
		
		// other pins
		zigBeePins.add(new XBeePin("VCC", 1, null, null, null, "Power Supply", (Capability[])null));
		zigBeePins.add(new XBeePin("DOUT", 2, null, null, null, "UART Data Out", (Capability[])null));
		zigBeePins.add(new XBeePin("DIN", 3, null, null, null, "UART Data In", (Capability[])null));
		zigBeePins.add(new XBeePin("RESET", 5, null, null, null, "Module Reset (reset pulse must be at least 200 ns)", (Capability[])null));
		zigBeePins.add(new XBeePin("[reserved]", 8, null, null, null, "Do not connect", (Capability[])null));
		// DIO8 not supported according to manual
		zigBeePins.add(new XBeePin("DTR/SLEEP_RQ", 9, null, null, null, "Pin Sleep Control Line", (Capability[])null));
		zigBeePins.add(new XBeePin("GND", 10, null, null, null, "Ground", (Capability[])null));
		// DIO9 not supported according to manual
		zigBeePins.add(new XBeePin("ON/SLEEP", 13, null, null, null, "Module Status Indicator", (Capability[])null));
		zigBeePins.add(new XBeePin("VREF", 14, null, null, null, "Not used on this module. For compatibility with other XBee modules, we recommend connecting this pin to a voltage reference if Analog sampling is desired. Otherwise, connect to GND", (Capability[])null));
	
		Collections.sort(zigBeePins, new PinSorter());
	}
	
	/**
	 * Sorts by pin number
	 * 
	 * @author andrew
	 *
	 */
	@SuppressWarnings("rawtypes")
	private static class PinSorter implements Comparator {
		public int compare(Object o1, Object o2) {
			return ((XBeePin)o1).getPin().compareTo(((XBeePin)o2).getPin());
		}		
	}
	
	public static List<XBeePin> getZigBeePins() {
		return zigBeePins;
	}
	
	private final static List<XBeePin> wpanPins = new ArrayList<XBeePin>();
	
	static { 
		wpanPins.add(new XBeePin("DTR/SLEEP_RQ/DI8", 9, "D8", 8, Capability.DISABLED, "Pin Sleep Control Line or Digital Input 8", Capability.DISABLED, Capability.DIGITAL_INPUT));
		wpanPins.add(new XBeePin("CTS/DIO7", 12, "D7", 7, Capability.CTS_FLOW_CTRL, "Clear-to-Send Flow Control or Digital I/O 7", Capability.DISABLED, Capability.CTS_FLOW_CTRL, Capability.DIGITAL_INPUT, Capability.DIGITAL_OUTPUT_LOW, Capability.DIGITAL_OUTPUT_HIGH));
		wpanPins.add(new XBeePin("RTS/AD6/DIO6", 16, "D6", 6, Capability.DISABLED, "Request-to-Send Flow Control, Analog Input 6 or Digital I/O 6", Capability.DISABLED, Capability.RTS_FLOW_CTRL, Capability.DIGITAL_INPUT, Capability.DIGITAL_OUTPUT_LOW, Capability.DIGITAL_OUTPUT_HIGH));
		wpanPins.add(new XBeePin("Associate/AD5/DIO5", 15, "D5", 5, Capability.ASSOC_LED, "Associated Indicator, Analog Input 5 or Digital I/O 5", Capability.DISABLED, Capability.ASSOC_LED, Capability.ANALOG_INPUT, Capability.DIGITAL_INPUT, Capability.DIGITAL_OUTPUT_LOW, Capability.DIGITAL_OUTPUT_HIGH));
		wpanPins.add(new XBeePin("AD4/DIO4", 11, "D4", 4, Capability.DISABLED, "Analog Input 4 or Digital I/O 4", Capability.DISABLED, Capability.ANALOG_INPUT, Capability.DIGITAL_INPUT, Capability.DIGITAL_OUTPUT_LOW, Capability.DIGITAL_OUTPUT_HIGH));
		wpanPins.add(new XBeePin("AD3/DIO3", 17, "D3", 3, Capability.DISABLED, "Analog Input 3 or Digital I/O 3", Capability.DISABLED, Capability.ANALOG_INPUT, Capability.DIGITAL_INPUT, Capability.DIGITAL_OUTPUT_LOW, Capability.DIGITAL_OUTPUT_HIGH));
		wpanPins.add(new XBeePin("AD2/DIO2", 18, "D2", 2, Capability.DISABLED, "Analog Input 2 or Digital I/O 2", Capability.DISABLED, Capability.ANALOG_INPUT, Capability.DIGITAL_INPUT, Capability.DIGITAL_OUTPUT_LOW, Capability.DIGITAL_OUTPUT_HIGH));
		wpanPins.add(new XBeePin("AD1/DIO1", 19, "D1", 1, Capability.DISABLED, "Analog Input 1 or Digital I/O 1", Capability.DISABLED, Capability.ANALOG_INPUT, Capability.DIGITAL_INPUT, Capability.DIGITAL_OUTPUT_LOW, Capability.DIGITAL_OUTPUT_HIGH));
		wpanPins.add(new XBeePin("AD0/DIO0", 20, "D0", 0, Capability.DISABLED, "Analog Input 0 or Digital I/O 0", Capability.DISABLED, Capability.ANALOG_INPUT, Capability.DIGITAL_INPUT, Capability.DIGITAL_OUTPUT_LOW, Capability.DIGITAL_OUTPUT_HIGH));
		wpanPins.add(new XBeePin("PWM0/RSSI", 6, "P0", null, Capability.RSSI_PWM, "PWM Output 0 / RX Signal Strength Indicator", Capability.DISABLED, Capability.RSSI_PWM, Capability.PWM_OUTPUT));
		wpanPins.add(new XBeePin("PWM1", 7, "P1", null, Capability.DISABLED, "PWM Output 1", Capability.DISABLED,  Capability.RSSI_PWM, Capability.PWM_OUTPUT));
		
	
		// other pins
		wpanPins.add(new XBeePin("VCC", 1, null, null, null, "Power Supply", (Capability[])null));
		wpanPins.add(new XBeePin("DOUT", 2, null, null, null, "UART Data Out", (Capability[])null));
		wpanPins.add(new XBeePin("DIN/CONFIG", 3, null, null, null, "UART Data In", (Capability[])null));
		wpanPins.add(new XBeePin("DO8", 4, null, null, null, "Digital Output 8 (not supported as of 2/28/09)", (Capability[])null));
		wpanPins.add(new XBeePin("RESET", 5, null, null, null, "Module Reset (reset pulse must be at least 200 ns)", (Capability[])null));
		wpanPins.add(new XBeePin("[reserved]", 8, null, null, null, "Do not connect", (Capability[])null));
		wpanPins.add(new XBeePin("GND", 10, null, null, null, "Ground", (Capability[])null));
		wpanPins.add(new XBeePin("ON/SLEEP", 13, null, null, null, "Module Status Indicator", (Capability[])null));
		wpanPins.add(new XBeePin("VREF", 14, null, null, null, "Voltage Reference for A/D Inputs", (Capability[])null));
		
		Collections.sort(wpanPins, new PinSorter());
	}
	
	public static String printAll(List<XBeePin> pins, String delimiter) {
		
		StringBuffer sb = new StringBuffer();
		
		sb.append(delimiter);
		sb.append("*Pin #*");
		sb.append(delimiter);
		sb.append("*AT Command*");
		sb.append(delimiter);
		sb.append("*Description*");
		sb.append(delimiter);
		sb.append("*Default Configuration*");
		sb.append(delimiter);
		sb.append("*Supported Configurations (Value)*");
		sb.append(delimiter);
		sb.append("*Analog I/O Method*");
		sb.append(delimiter);
		sb.append("*Digital I/O Method*");
		sb.append(delimiter);
		
		for (XBeePin pin : pins) {
			sb.append(System.getProperty("line.separator"));
			
			sb.append(delimiter);
			sb.append(pin.getPin());
			sb.append(delimiter);
			sb.append(pin.getAtCommand() == null ? "n/a" : pin.getAtCommand());
			sb.append(delimiter);
			sb.append(pin.getDescription());
			sb.append(delimiter);
			sb.append(pin.getDefaultCapability() == null ? "n/a" : pin.getDefaultCapability());
			sb.append(delimiter);
			
			boolean first = false;
			
			for (Capability cap : pin.getCapabilities()) {
				if (!first) {
					first = true;
				} else {
					sb.append(", ");
				}
				
				sb.append(cap + " (0x" + cap.getValue() + ")");
				//sb.append(cap);
			}
		
			sb.append(delimiter);
			
			// analog methods
			if (pin.getCapabilities().contains(Capability.ANALOG_INPUT)) {
				sb.append("getAnalog" + pin.getAtPin() + "()");
			} else {
				sb.append("n/a");
			}

			sb.append(delimiter);
			
			// digital methods
			if (pin.getCapabilities().contains(Capability.DIGITAL_INPUT)) {
				sb.append("isD" + pin.getAtPin() + "On()");
			} else {
				sb.append("n/a");
			}
			
			sb.append(delimiter);
		}
		
		return sb.toString();
	}
	
	public static List<XBeePin> getWpanPins() {
		return wpanPins;
	}
	
	public static void main(String[] args) {
		// print for wiki table
		System.out.println(Capability.printAll("|| "));
		
		System.out.println("Series 1:");
		System.out.println(printAll(wpanPins, "|| "));
		System.out.println("Series 2:");
		System.out.println(printAll(zigBeePins, "|| "));
	}
}

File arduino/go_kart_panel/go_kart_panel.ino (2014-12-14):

/**
* Project Go-Kart Control / Go-Kart Panel
* @author	Gerd Bartelt - www.sebulli.com
*
* @copyright	GPL3
*
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
*/

// http://playground.arduino.cc/uploads/Code/TimerOne.zip
#include "TimerOne.h"
#include <avr/wdt.h>

// Firmware version will be displayed after reset
#define SW_VERSION 003

int RESET_Pin  = 9;

int timeoutCnt = 0;
int timeout = 1000; // 0.1s steps (600 = 1min)
boolean isTimeout = false;
boolean is100msTick = false;
uint8_t mcusr = 0;
uint32_t magicCode __attribute__ ((section (".noinit"))); 
boolean wasTimeoutReset = false;
int rebootState = 0;
int rebootCnt = 0;
/**
 * The setup for the whole project
 *
 */
void setup() {
  
  pinMode(RESET_Pin, OUTPUT); 
  digitalWrite(RESET_Pin, HIGH);
   
  // Was it a timeout reset?
  wasTimeoutReset = (magicCode == 0xAA5500FF);
  magicCode = 0;
    
  Timer1.initialize(100000);
  Timer1.attachInterrupt(task100ms);
  
  // initialize the power module
  Power_Init();
  
  // initialize the display module
  Display_Init();
  
  // initialize the radio module
  Radio_Init();
  
  // Restart the timeout after the initialization
  timeoutCnt = 0;
  

}


/**
 * The main loop
 *
 */
void loop() {
  Power_Task();
  Radio_Task();
  
  // Generate a 100ms task
  if (is100msTick) {
    Display_Task_100ms();
    rebootTask();
    is100msTick = false;
  }
  
}

/**
 * The 100ms task
 *
 */
void task100ms() {

  // Timeout counter
  if (timeoutCnt < timeout) {
    timeoutCnt ++;
    isTimeout = false;
  }
  else {
    isTimeout = true;
  }

  is100msTick = true;
  
}

/*
 * State machine to reboot the system
 *
 */
void rebootTask() {
  
  // Reboot mechanism
  switch (rebootState) {
    
    // Wait
    case 0:
      if (isTimeout) {
        rebootState = 1;
        rebootCnt = 0;
      }
      break;

    // Reset the XBee module
    case 1:
      Display_Clear();
      digitalWrite(RESET_Pin, LOW);
      rebootCnt ++;
      if (rebootCnt > 5) {
        rebootState = 2;
        rebootCnt = 0;
      }
         
      break;
      
    // Reboot  
    case 2:
      digitalWrite(RESET_Pin, HIGH);
      magicCode = 0xAA5500FF;
      wdt_enable(WDTO_15MS);
      while(1);
         
      break;

   }
}

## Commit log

2014-11-08 Changed directory structure Added hardware folder Added picture folder
    [gokart.csv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]
2014-11-20 Added some picture, improved error messages and new setting
    [gokart.sch]
2014-11-23 First arduino firmware
2014-11-24 Use of the arduino's shiftOut() function
2014-11-25 Arduino: Read the battery voltage and scale it to 0.1V
2014-11-26 Arduino: Undervoltage detection and timeout handling
2014-11-26 Arduino: new XBee radio module
2014-11-27 Bugfix: Setting power value
    [display.ino, go_kart_panel.ino, radio.ino]
2014-11-29 Adruino V100: Set AP2 mode, accept only master frames, show own addr Updates settings.txt with 2 slave addresses
2014-11-30 Added schematic files for both variants.
2014-12-07 Added test mode, voltage calibration and possibility to enable/disable pannels.
2014-12-14 GUI Version 1.2.0 Arduino Version 003 Fix power setting for complete setup Resetting the XBee module after transmit timeout errors
    [XBee.java]
2014-12-14 Updated hardware
    [gokart.csv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]

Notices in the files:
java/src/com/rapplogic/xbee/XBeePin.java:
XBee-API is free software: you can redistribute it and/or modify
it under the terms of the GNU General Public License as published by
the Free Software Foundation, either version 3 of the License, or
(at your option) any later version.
